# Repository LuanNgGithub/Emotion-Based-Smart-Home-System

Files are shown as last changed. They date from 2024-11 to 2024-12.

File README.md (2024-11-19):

# Emotion-Adaptive Smart Home
Repository for Emotion-Adaptive Smart Home

[Project management (Team 06)](https://pushgd10re5p.larksuite.com/base/LZFZbZlYla9m4zsmLQGupiIKs9e?table=tbl0MZkUSxeu3IoC&view=vewp7nmiS4)

Check out our Wiki for our latest update!
[Wiki](https://github.com/LuanNgGithub/Emotion-Based-Smart-Home-System/wiki)

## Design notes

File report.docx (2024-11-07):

Project Name: Emotion-Based Smart Home System

Current Progress: Today, we successfully set up the environment on the Jetson Orin Nano and configured the GPIO ports. For an initial test, we used a breadboard with an LED (since we haven't purchased a light strip yet) to demonstrate that the light turns on when a "neutral" expression is detected.

Technical Breakthroughs:

1. Successfully accessed the camera for real-time video streaming.
2. Implemented YOLO-based emotion detection in real-time to analyze facial expressions in the video feed.
3. Enabled LED control based on detected emotional states, achieving a basic emotional feedback mechanism.

Code Implementation: Our code employs a voting mechanism to aggregate emotions over a defined window. When "Happy" exceeds a set threshold, the GPIO interface controls the LED to turn on. Key modules include:

1.Real-time video processing and emotion detection.

2.Emotion voting mechanism based on a sliding window to ensure accurate feedback.

3.GPIO control for LED response, triggering based on the detection of specific emotions (e.g., " neutral ").

Next Steps: We plan to purchase a light strip to extend the system, enabling it to display different colors as feedback for various emotions, enhancing both interactivity and expressiveness.

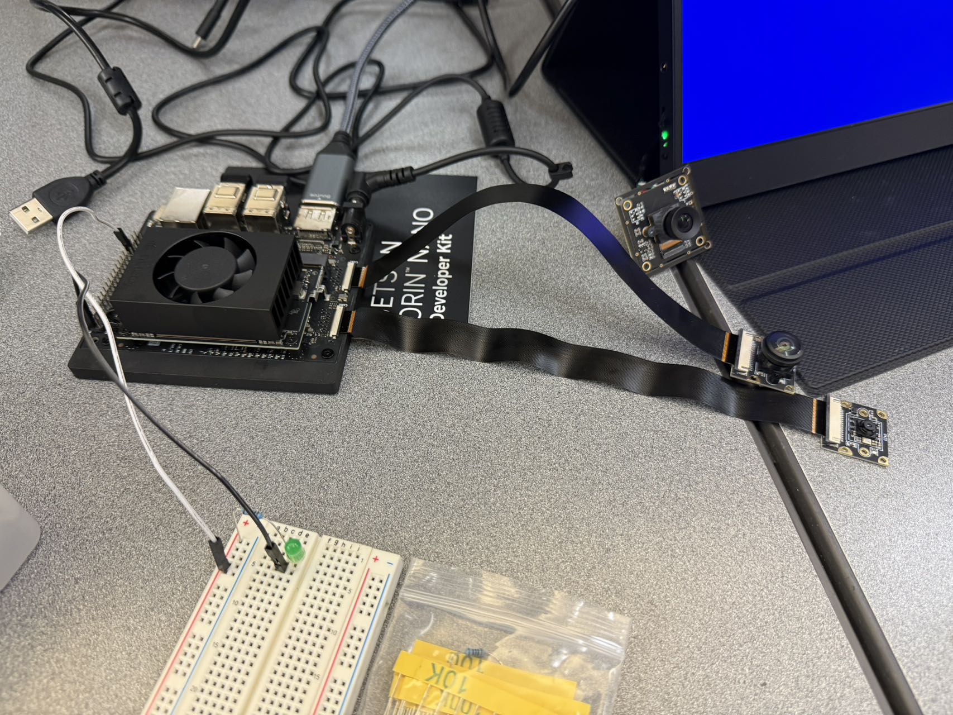
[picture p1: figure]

The image shows our Jetson Orin Nano board, LED, and the camera setup demonstrating real-time emotion feedback

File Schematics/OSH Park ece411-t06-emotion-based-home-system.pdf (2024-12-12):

## OSH Park ~ ece411-t06-emotion-based-home-system

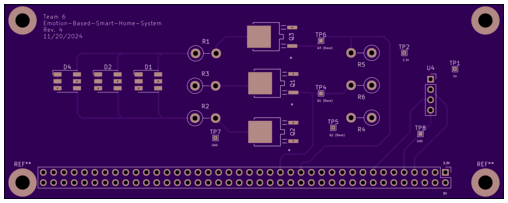
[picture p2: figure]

### Board Top

This shows the final manufactured board as if you held it in your hand.

Your design should show gold copper, purple mask, white silk, black drills, and the board outline.

Internal cutouts are indicated by a black outline but are not filled in.

If the image here is entirely white, you'll want to find and fix any gaps in the board outline.

There should be no dimension or measurement ruler

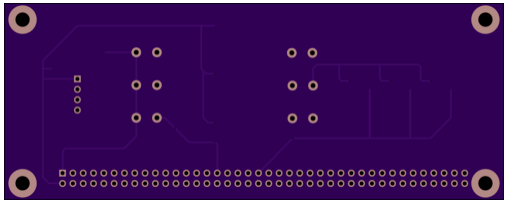
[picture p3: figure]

### Board Bottom

This shows the final manufactured board as if you held it in your hand.

Your design should show gold copper, purple mask, white silk, black drills, and the board outline.

Internal cutouts are indicated by a black outline but are not filled in.

If the image here is entirely white, you'll want to find and fix any gaps in the board outline.

There should be no dimension or measurement ruler

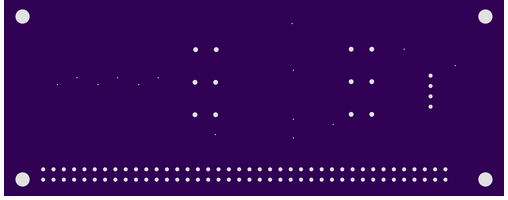
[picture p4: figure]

Rendered from "411 Schematic-PTH.drl"

### Drills

Drills should show up as white circles or dots on a purple background.

Drill files should be NC Drill or Excellon format files. Multiple files will be accepted, and merged into one for fabrication.

Drill hits that pass through copper will be plated. All other drill hits will be non-plated.

Most drill formats are detected and displayed as you'd see on the board. If your drills look incorrect, try exporting with INCH units and either No Zero Suppression or Leading Zero Suppression.

Drill slots and "oval" drills included as part of the drill file are supported. Most design tools do this when using the tool's native slot commands. Supported slots will appear on this preview.
Note, it's possible to use this supported callout in an unsupported way. See our Cutouts and Slots (https://docs.oshpark.com/submitting-orders/cutouts-and-slots/) page for details regarding unsupported applications of slot drill commands.

Drills sizes below our minimums will be increased to the minimum size. See the design rules (https://docs.oshpark.com/services/) or our drills help page. (https://docs.oshpark.com/submitting-orders/drill-specs/) for additional details on drill specs.
Additionally, the following are not supported.
- Overlapping drill hits
- Blind or buried vias

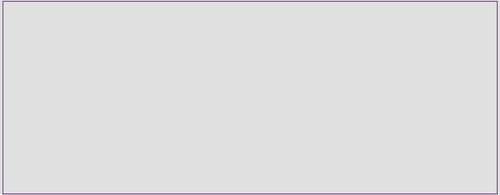
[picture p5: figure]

Rendered from "build3/411 Schematic-Edge_Cuts.gbr"

### Board Outline

The board outline should be a watertight purple outline showing at least the edge of the board with no gaps.

We will cut non-rectangular board shapes, but you will be billed for the smallest rectangle that will encompass the design.
As an example, a 2in diameter circle is billed the same as a 2in by 2in square.

Non-plated Board Cutouts (https://docs.oshpark.com/submitting-orders/board-outline/) can be represented on the board outline layer, with some limitations.
Slots are unsupported when indicated on the board outline layer, but usually work. To make slots with full support, use Drill Slots (https://docs.oshpark.com/submitting-orders/slots/) on the drill layer.

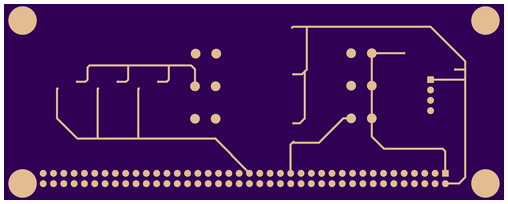
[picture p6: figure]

Rendered from "build3/411 Schematic-B_Cu.gbr"

### Bottom Layer

This layer should appear 'mirrored' as if you were looking down on it through the board from the top.

We will place copper everywhere we see gold color on this layer.

If you are using Altium Designer or Altium CircuitMaker, carefully examine the board to make sure there are no shorts from the mechanical layers being included on this layer. See here (https://docs.oshpark.com/design-tools/altium-designer/) for more.

If you are using Eagle, be aware that airwires are not the same as routed traces. If there are no copper links between pads showing on this layer, please review your .brd file for airwires.

See our design tools pages (https://docs.oshpark.com/design-tools/) for more.

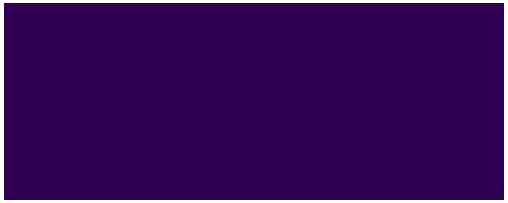
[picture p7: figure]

Rendered from "build3/411 Schematic-B_Silkscreen.gbr"

### Bottom Silk Screen

This layer should appear 'mirrored' as if you were looking down on it through the board from the top.

We will ignore the portion of the silkscreen that extends beyond the board outline.

We will automatically remove any silkscreen that crosses drilled holes or exposed copper.

If a logo isn't showing up on this layer, try changing your design tool import settings to create that silk image with 400 DPI or less, or check out our Eagle-specific import-bmp script (https://docs.oshpark.com/submitting-orders/import-bmp/) instructions.

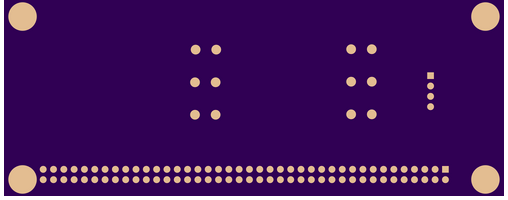
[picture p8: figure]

Rendered from "build3/411 Schematic-B_Mask.gbr"

### Bottom Solder Mask

This layer should appear 'mirrored' as if you were looking down on it through the board from the top.

Soldermask layers show us where to remove the purple solder resist. The gold-colored areas will be exposed on the final board, and purple areas will be covered.

If you submitted an empty file, we won't remove any mask so this entire side of the board will be covered in purple soldermask

To expose the entire board, submit this file with a single polygon that covers the entire board. We will remove all mask everywhere and expose all the copper and board substrate.

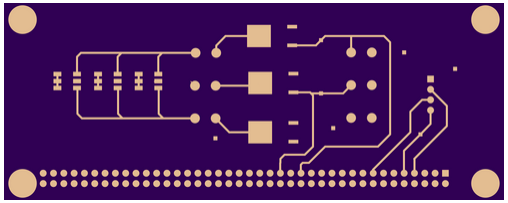
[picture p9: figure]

Rendered from "build3/411 Schematic-F_Cu.gbr"

### Top Layer

We will place copper everywhere we see gold color on this layer.

If you are using Altium Designer or Altium CircuitMaker, carefully examine the board to make sure there are no shorts from the mechanical layers being included on this layer. See here (https://docs.oshpark.com/design-tools/altium-designer/) for more.

If you are using Eagle, be aware that airwires are not the same as routed traces. If there are no copper links between pads showing on this layer, please review your .brd file for airwires.

See our design tools pages (https://docs.oshpark.com/design-tools/) for more.

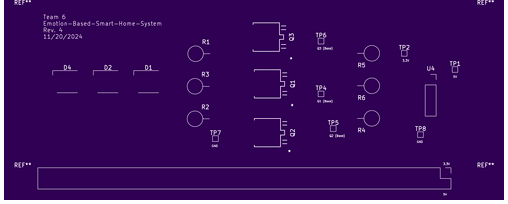
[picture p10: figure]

Rendered from "build3/411 Schematic-F_Silkscreen.gbr"

### Top Silk Screen

We will ignore the portion of the silkscreen that extends beyond the board outline.

We will automatically remove any silkscreen that crosses drilled holes or exposed copper.

If a logo isn't showing up on this layer, try changing your design tool import settings to create that silk image with 400 DPI or less, or check out our Eagle-specific import-bmp script (https://docs.oshpark.com/submitting-orders/import-bmp/) instructions.

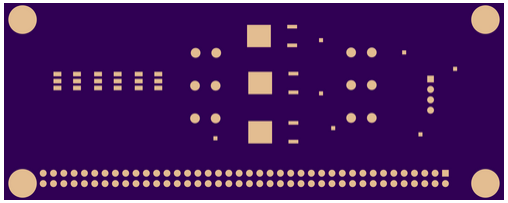
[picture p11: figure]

Rendered from "build3/411 Schematic-F_Mask.gbr"

### Top Solder Mask

Soldermask layers show us where to remove the purple solder resist. The gold-colored areas will be exposed on the final board, and purple areas will be covered.

If you submitted an empty file, we won't remove any mask so this entire side of the board will be covered in purple soldermask

To expose the entire board, submit this file with a single polygon that covers the entire board. We will remove all mask everywhere and expose all the copper and board substrate.

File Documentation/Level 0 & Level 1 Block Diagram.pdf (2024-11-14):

Level 0 Block Diagram

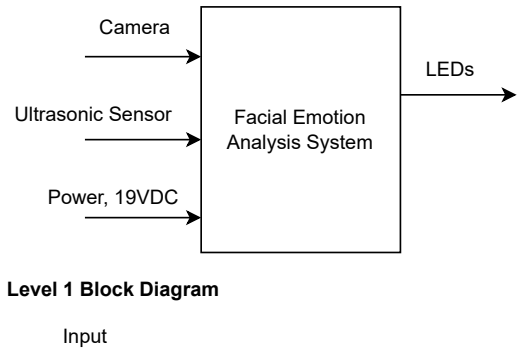
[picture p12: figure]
LEDs; Facial Emotion Analysis System; Camera; Ultrasonic Sensor; Input; Power, 19VDC; Level 1 Block Diagram
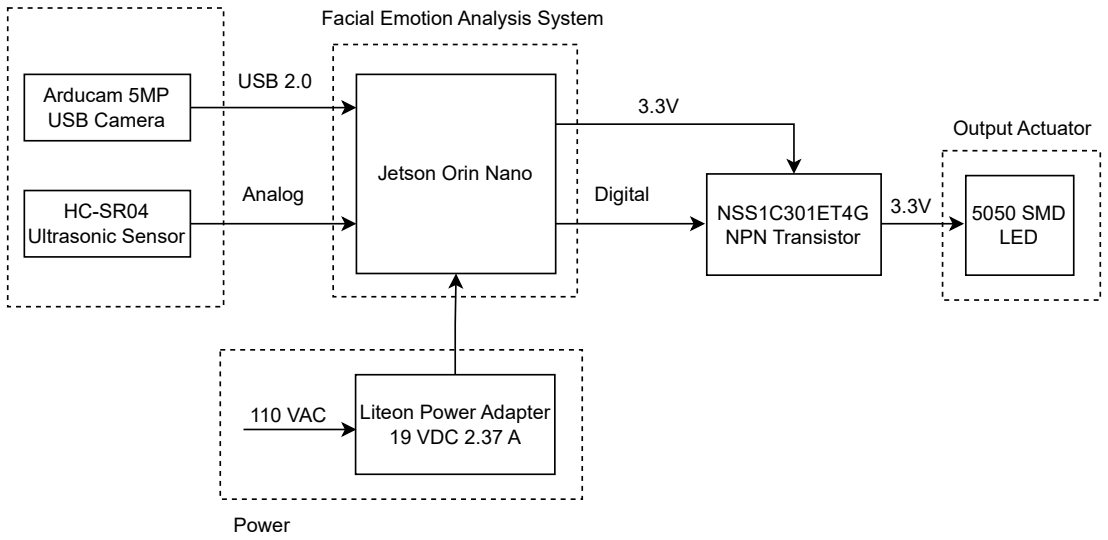
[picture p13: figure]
Jetson Orin Nano; HC-SR04 Ultrasonic Sensor; Arducam 5MP USB Camera; USB 2.0; Analog; Digital; Facial Emotion Analysis System; Liteon Power Adapter 19 VDC 2.37 A; 110 VAC; NSS1C301ET4G NPN Transistor; 5050 SMD LED; Output Actuator; Power

Team 6 - Emotion-Based-Smart-Home-System Kamal, Kilo, Samuel, Luan

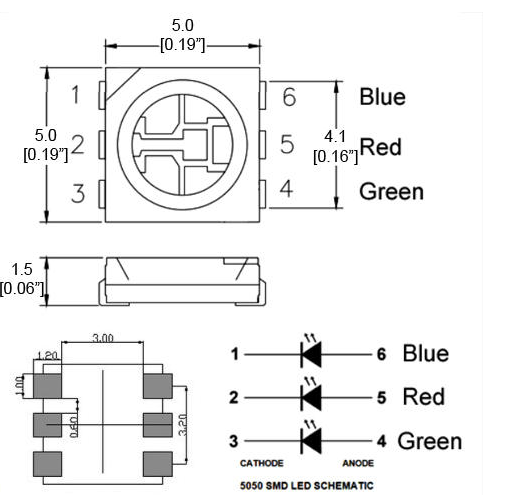
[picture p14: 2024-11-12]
Documentation/5050 SMD LED Pinout.png

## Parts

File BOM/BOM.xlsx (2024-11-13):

Bill Of Materials for: 06 Emotion-Based-Smart-Home-System
Last modified: 11/12/2024
PCB verison: #1
BOM revision: #1
Cnt | Name | P/NP | Mfg | Mfg PN | Description | Dist | Dist Part Number | Cost Ea. | Cost Total
1 | NVIDIA® Jetson Orin™ Nano Developer Kit | P | NVIDIA | J3010 | a compact edge AI board | Seeed Studio | 102110839 | $499 | $499
1 | NVMe M.2 2280 SSD 1TB | P | Kioxia | M.2280 1TB | 1TB PCIe NVMe Gen 3x4 SSD, includes a heatsink suitable for 2280 SSDs | Seeed Studio | 112990267 | $74.99 | $74.99
1 | Arducam 5MP Autofocus USB Camera Module | P | Arducam | B0441 | 2592(H)×1944(V)@30fps, mini camera for Linux | Amazon | B08ZR8KNXT | $34.99 | $34.99
1 | Chanzon 100 pcs 5050 WS2812B SMD RGB Tricolor LED Diode Lights | P | Chanzon | WS2812B | RGB multicolor LED, 6-pin, 16mA, DC 3.7V-5.3V, wide viewing angle of 120 degrees | Amazon | B09J4KDYY3 | $9.99 | $9.99
10 | NSS1C301ET4G | P | Onsemi | NSS1C301ET4G | NPN Transistor, 100V, 3A, DPAK, 2.1W Surface Mount | Digi-Key | NSS1C301ET4GOSCT-ND | $0.81 | $8.10
1 | Ultrasonic Sensor Module HCSR-04 | NP | Gearbox Labs | PART HCSR-04 | Ultrasonic Sensor, 40kHz, Generic Distance Sensor | Digi-Key | 4166-PARTHCSR-04-ND | $5.00 | $5.00
1 | IRLB8721PbF | P | Infineon Technologies | IRLB8721PbF | N-Channel MOSFET, 30V, 62A, TO-220AB, 65W, Through Hole | Digi-Key | IRLB8721PBF-ND | $1.57 | $1.57

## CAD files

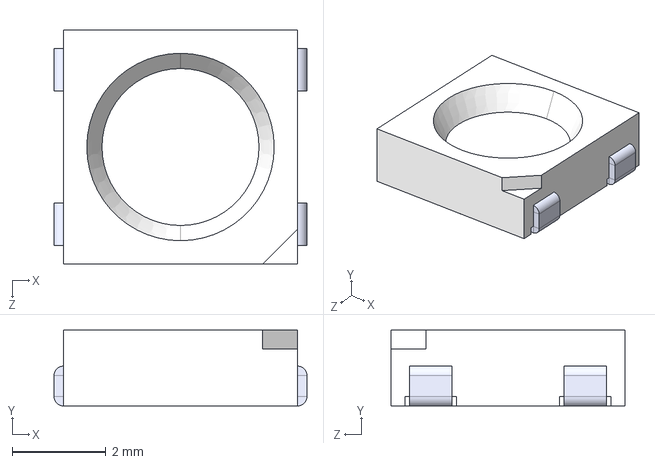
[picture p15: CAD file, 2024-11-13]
Footprints/SMD-RGB-HI-LIGHT_6P-L5.0_W5.0_H1.5MM_/SMD-RGB-HI-LIGHT_6P-L5.0_W5.0_H1.5MM_.step
5.40 x 1.62 x 5.00 mm

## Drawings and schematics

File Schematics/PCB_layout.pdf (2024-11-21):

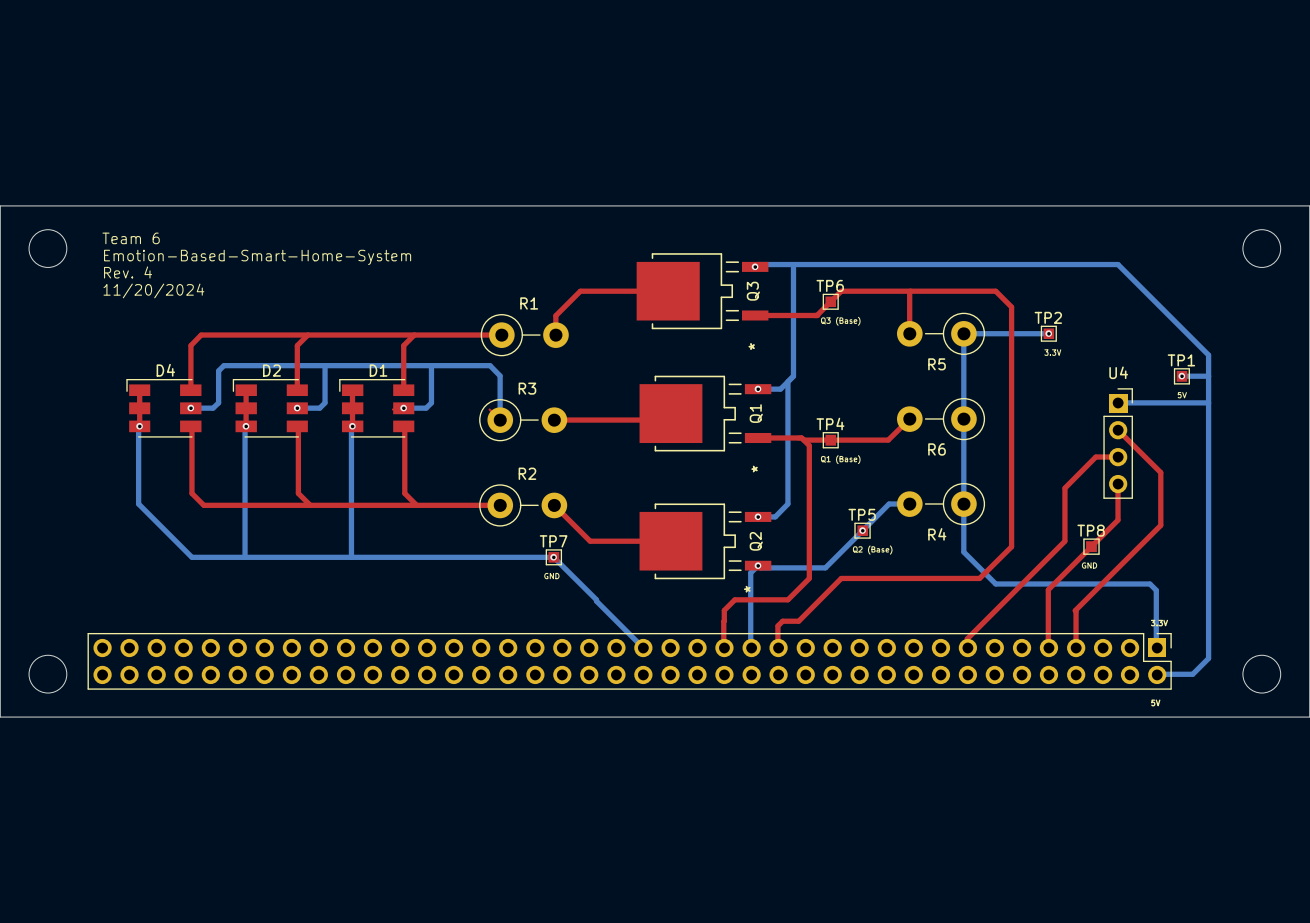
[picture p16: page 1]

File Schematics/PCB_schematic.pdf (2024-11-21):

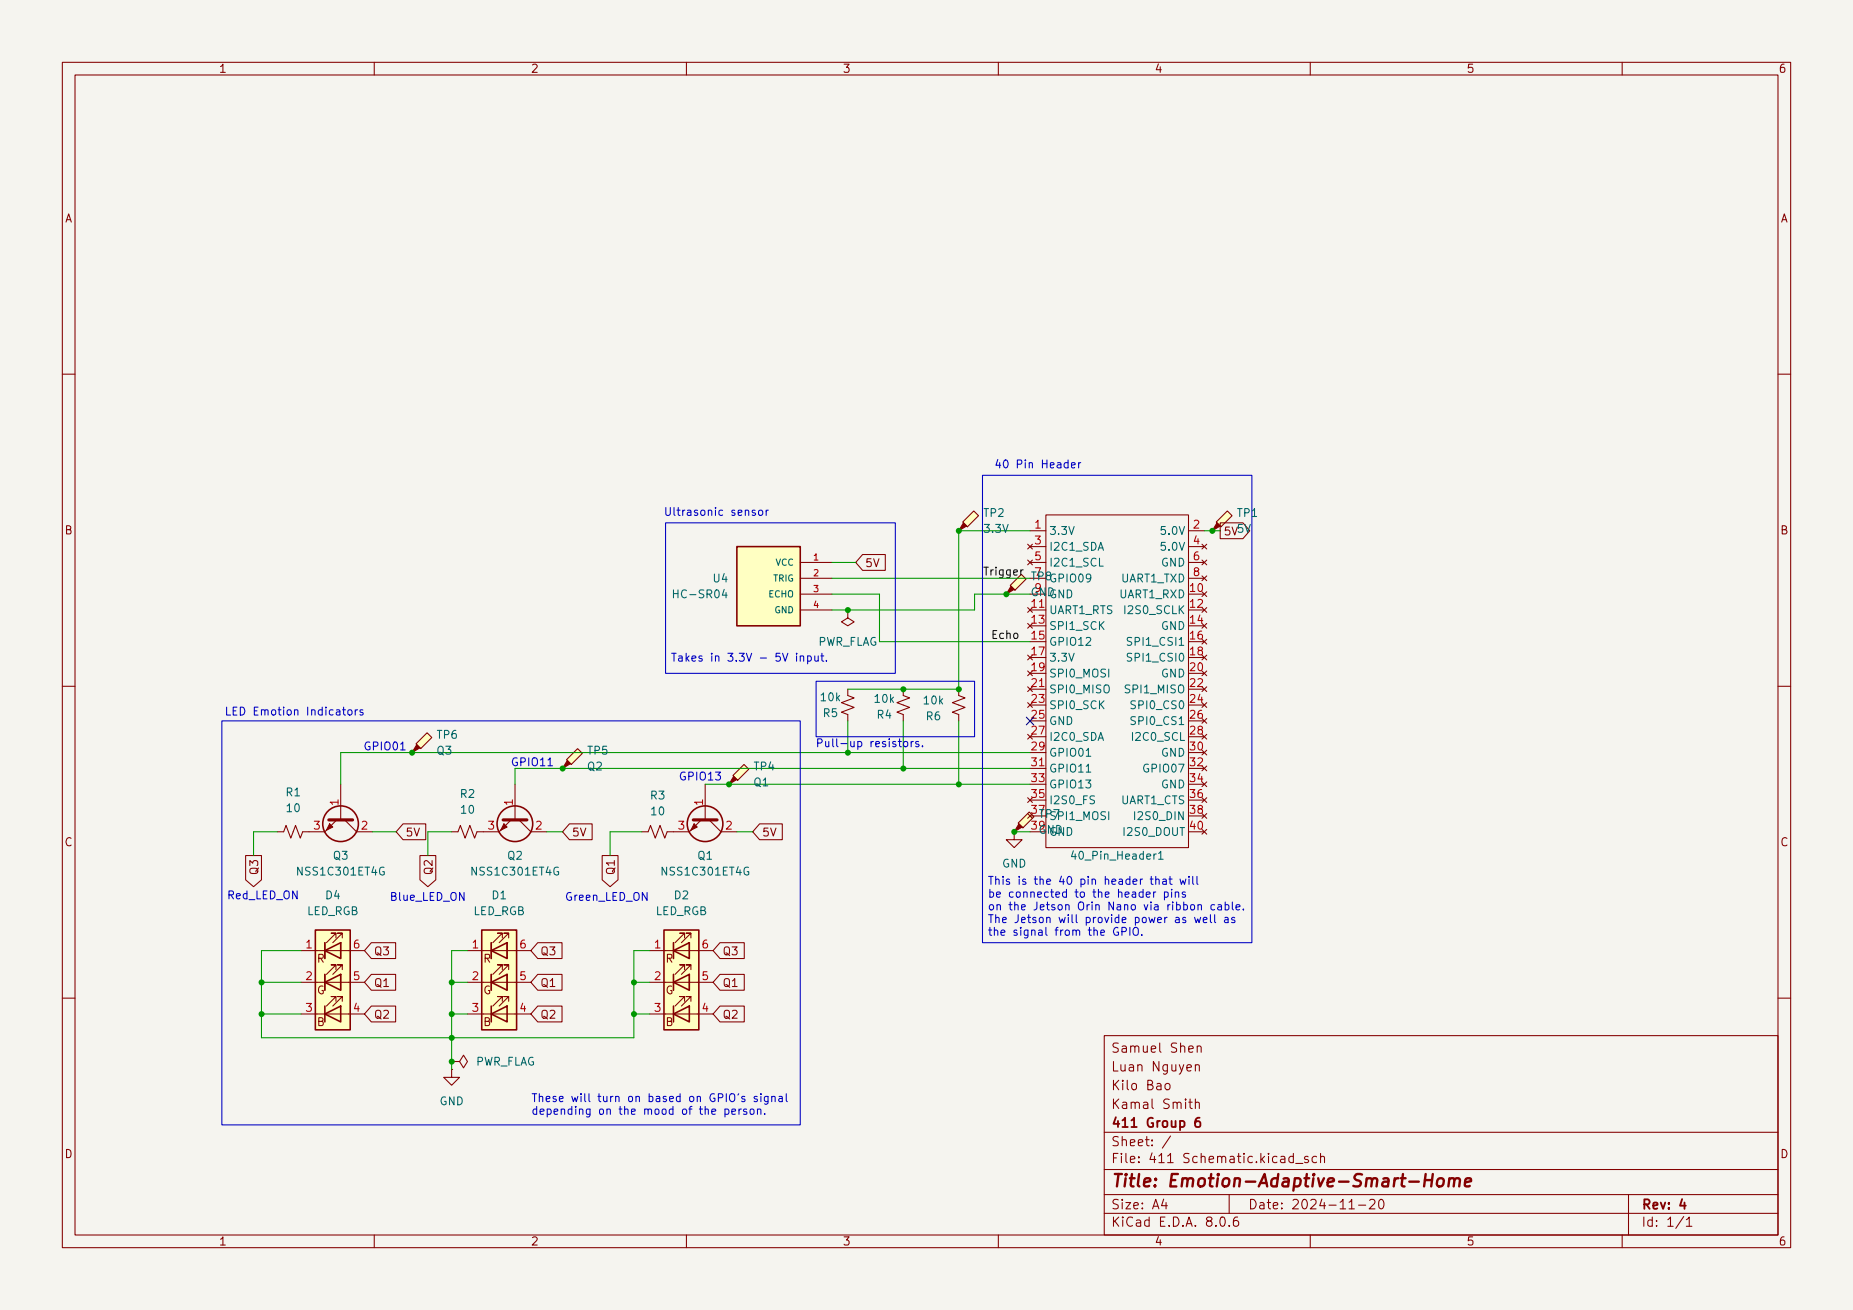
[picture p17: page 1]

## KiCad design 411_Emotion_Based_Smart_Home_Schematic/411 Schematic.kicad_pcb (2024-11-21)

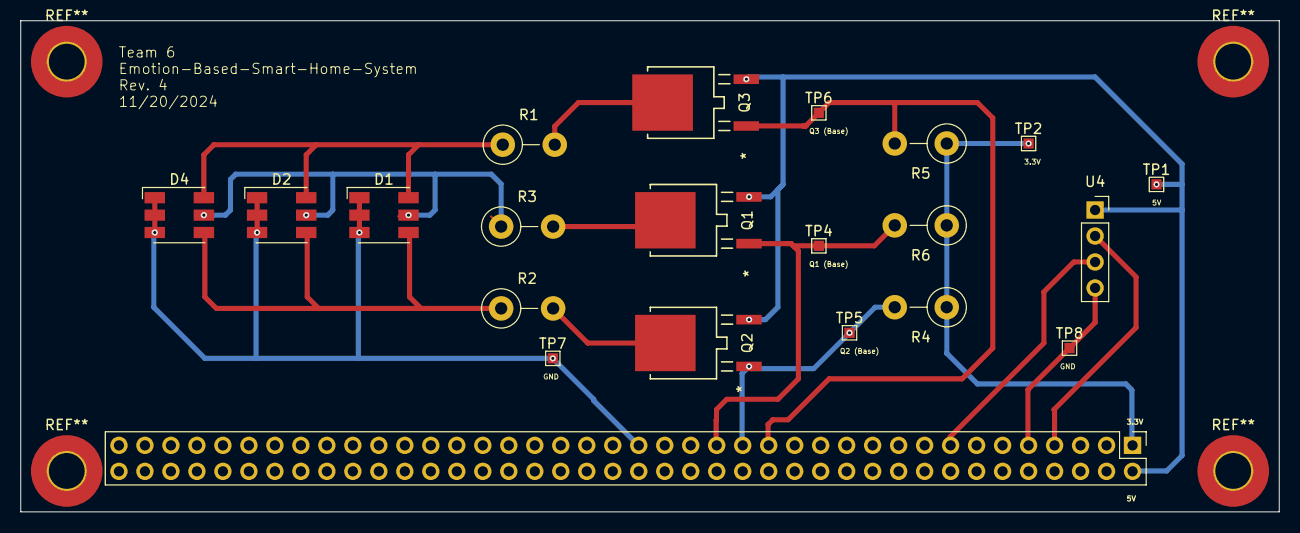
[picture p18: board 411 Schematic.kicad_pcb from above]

Board: 2 copper layers, 123.0 x 48.0 mm, 21 parts (0 on the bottom side), 15 nets.

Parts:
40_Pin_Header1: PinHeader_2x40_P2.54mm_Vertical
D1, D2, D4: LED_RGB; LED_RGB_5050-6
Q1, Q2, Q3: NSS1C301ET4G; DPAK-4_6P22X6P73_ONS
R1, R2, R3: 10; R_Axial_DIN0411_L9.9mm_D3.6mm_P5.08mm_Vertical
R4, R5, R6: 10k; R_Axial_DIN0411_L9.9mm_D3.6mm_P5.08mm_Vertical
TP1: 5V; TestPoint_Pad_1.0x1.0mm
TP2: 3.3V; TestPoint_Pad_1.0x1.0mm
TP4: Q1; TestPoint_Pad_1.0x1.0mm
TP5: Q2; TestPoint_Pad_1.0x1.0mm
TP6: Q3; TestPoint_Pad_1.0x1.0mm
TP7, TP8: GND; TestPoint_Pad_1.0x1.0mm
U4: HC-SR04; PinSocket_1x04_P2.54mm_Vertical

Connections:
5V: 40_Pin_Header1.2 (5.0V), Q1.2 (C), Q2.2 (C), Q3.2 (C), TP1.1, U4.1 (VCC)
/Echo: 40_Pin_Header1.15 (GPIO12), U4.3 (ECHO)
/Trigger: 40_Pin_Header1.7 (GPIO09), U4.2 (TRIG)
GND: 40_Pin_Header1.39 (GND), D1.1 (RK), D1.2 (GK), D1.3 (BK), D2.1 (RK), D2.2 (GK), D2.3 (BK), D4.1 (RK), D4.2 (GK), D4.3 (BK), TP7.1
unnamed: 40_Pin_Header1.1 (3.3V), R4.1, R5.1, R6.1, TP2.1
unnamed: 40_Pin_Header1.29 (GPIO01), Q3.1 (B), R5.2, TP6.1
unnamed: 40_Pin_Header1.31 (GPIO11), Q2.1 (B), R4.2, TP5.1
unnamed: 40_Pin_Header1.33 (GPIO13), Q1.1 (B), R6.2, TP4.1
unnamed: Q1.3 (E), R3.2
unnamed: Q2.3 (E), R2.2
unnamed: Q3.3 (E), R1.2
unnamed: 40_Pin_Header1.9 (GND), TP8.1, U4.4 (GND)
Q1: D1.5 (GA), D2.5 (GA), D4.5 (GA), R3.1
Q2: D1.4 (BA), D2.4 (BA), D4.4 (BA), R2.1
Q3: D1.6 (RA), D2.6 (RA), D4.6 (RA), R1.1

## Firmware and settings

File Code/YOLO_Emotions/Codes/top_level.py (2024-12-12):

import os
import time
import subprocess
import logging
import Jetson.GPIO as GPIO

#sudo systemctl enable top_level.service
#sudo systemctl stop top_level.service



# 配置日志
logging.basicConfig(filename="/home/jetson/Desktop/recording.log",
                    level=logging.INFO,
                    format="%(asctime)s - %(levelname)s - %(message)s")

# 初始化 GPIO, 用于状态显示和超声波传感器
LED_STATUS_PIN = 15  # 显示进程状态的 LED 引脚
GPIO_TRIGGER = 7  # 超声波传感器 Trig 引脚###################Test the trigger first
GPIO_ECHO = 32  # 超声波传感器 Echo 引脚


GPIO.cleanup()
GPIO.setmode(GPIO.BOARD)
GPIO.setup(LED_STATUS_PIN, GPIO.OUT, initial=GPIO.LOW)
GPIO.setup(GPIO_TRIGGER, GPIO.OUT, initial=GPIO.LOW)
GPIO.setup(GPIO_ECHO, GPIO.IN)

# 超声波测距函数
def measure_distance():
    # 发送高电平信号到 Trig 引脚
    GPIO.output(GPIO_TRIGGER, GPIO.HIGH)
    time.sleep(0.00001)
    GPIO.output(GPIO_TRIGGER, GPIO.LOW)

    # 记录发送超声波的时刻
    start_time = time.time()
    while GPIO.input(GPIO_ECHO) == 0:
        start_time = time.time()

    # 记录接收到返回超声波的时刻
    stop_time = time.time()
    while GPIO.input(GPIO_ECHO) == 1:
        stop_time = time.time()

    # 计算往返时间并转换为距离 (cm)
    time_elapsed = stop_time - start_time
    distance = (time_elapsed * 34300) / 2
    return distance





# 控制 LED 状态
#def set_led_status(is_running):
 #   GPIO.output(LED_STATUS_PIN, GPIO.HIGH if is_running else GPIO.LOW)
  #  GPIO.output(LED_PIN, GPIO.HIGH)  # 设置 LED 引脚为高电平，保持亮




# 主进程循环
def main_loop():
    yolo_process = None
    GPIO.output(LED_STATUS_PIN, GPIO.HIGH)  # 设置 LED 引脚为高电平，保持亮
    try:
        while True:
            # 检查 YOLO 子进程是否已退出
            if yolo_process is not None and yolo_process.poll() is None:
                logging.info("YOLO process is still running.")
                time.sleep(1)  # 延迟检查
                continue

            # 测量距离
            dist = measure_distance()
            logging.info(f"Measured distance: {dist:.2f} cm")

            # 检查距离触发条件80cm
            if dist < 80:
                logging.info("Trigger condition met (distance < 80cm). Starting YOLO process...")
                yolo_process = subprocess.Popen(["python3", "/home/jetson/Documents/test/programm.py"])
          
            else:

                logging.info("No trigger condition met. Waiting...")

            time.sleep(1)  # 主循环间隔

    except KeyboardInterrupt:
        logging.info("Process manager stopped by user.")
    except Exception as e:
        logging.error(f"Unexpected error: {e}")
    finally:
        if yolo_process is not None:
            yolo_process.terminate()
        GPIO.cleanup()


if __name__ == "__main__":
    main_loop()

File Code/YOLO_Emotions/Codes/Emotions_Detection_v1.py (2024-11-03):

import cv2
from ultralytics import YOLO  # 确保这个import语句与您的实际环境相匹配

# 加载YOLOv8模型：人脸检测模型和表情识别模型
face_model = YOLO('/Users/muse/Documents/YOLO_Emotions/Test/weights/yolo_face.pt')  # 人脸检测模型
emotion_model = YOLO('/Users/muse/Documents/YOLO_Emotions/Test/weights/yolo11s/best.pt')  # 表情识别模型

# 打开摄像头
cap = cv2.VideoCapture(0)

# 设置视频流的分辨率为1080p (1920x1080)
cap.set(cv2.CAP_PROP_FRAME_WIDTH, 1920)
cap.set(cv2.CAP_PROP_FRAME_HEIGHT, 1080)

# 循环遍历视频帧
while cap.isOpened():
    # 从视频读取一帧
    success, frame = cap.read()

    if success:
        # 在帧上运行人脸检测，并设置置信度阈值和NMS IOU阈值
        face_results = face_model(frame, conf=0.7, iou=0.5)

        # 迭代每个检测到的人脸框
        for face in face_results:
            # 获取人脸的坐标框信息
            for box in face.boxes:
                # 提取人脸区域
                x1, y1, x2, y2 = map(int, box.xyxy[0])
                face_region = frame[y1:y2, x1:x2]

                # 在人脸区域内运行表情检测，并设置置信度阈值和NMS IOU阈值
                emotion_results = emotion_model(face_region, conf=0.7, iou=0.5)

                # 在人脸区域上展示表情检测的结果
                if len(emotion_results) > 0:
                    annotated_face = emotion_results[0].plot()

                    # 将注释后的脸部区域重新放回到原图上
                    frame[y1:y2, x1:x2] = annotated_face

        # 展示带注释的帧（包含人脸和表情）
        cv2.imshow("Emotions Detection", frame)

        # 如果按下'q'则退出循环
        if cv2.waitKey(1) & 0xFF in [27, ord('q')]:
            break
    else:
        # 如果视频结束则退出循环
        break

# 释放视频捕获对象并关闭显示窗口
cap.release()
cv2.destroyAllWindows()

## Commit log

2024-10-31 Create Ultrasonic Sensor
2024-11-07 Current updated schematic
    [Emotion-Based-Smart-Home-System.kicad_sch]
2024-11-07 Current Schematic
    This is the schematic that Luan and Kamal are actively working on
    [Emotion-Based-Smart-Home-System.kicad_sch]
2024-11-07 Updated Kicad design
    This is our updated kicad, we still need to add the speaker and finish the camera
    [Emotion-Based-Smart-Home-System.kicad_sch]
2024-11-07 Updated again
    Fixed an error and made the GND on the USB camera passive
    [Emotion-Based-Smart-Home-System.kicad_sch]
2024-11-07 Entire design folder
    We had to move this into it's own seperate file to get the PCB design to work. Will fix names later
    [411 Schematic.kicad_pcb, 411 Schematic.kicad_sch, Emotion-Based-Smart-Home-System.kicad_sch]
2024-11-07 Updating our Schematic and Layout
    Altering things in the schematic and layout before we turn this in
    [411 Schematic.kicad_pcb]
2024-11-07 Delete 411_Emotion_Based_Smart_Home_Schematic/~411 Schematic.kicad_sch.lck
    Removing the Lock file
2024-11-07 Delete 411_Emotion_Based_Smart_Home_Schematic/~411 Schematic.kicad_pcb.lck
    Removing this lock file
2024-11-09 Added folder for ultrasonic sensor.
2024-11-09 Organized folders.
    [411 Schematic.kicad_pcb, 411 Schematic.kicad_sch, Emotion-Based-Smart-Home-System.kicad_sch]
2024-11-12 Added spec sheet for LED and BJT.
2024-11-13 Added folder for BOM and Footprint.
2024-11-13 Updating schematic
    Testing if this works
2024-11-13 Added LED RGB footprint
    [SMD-RGB-HI-LIGHT_6P-L5.0_W5.0_H1.5MM_.step]
2024-11-14 5050 LED Schematic.drawio
2024-11-14 5050 LED and Transistor Schematic.drawio
2024-11-14 Updating what I have of schematic
    [411 Schematic.kicad_sch]
2024-11-14 Updated the schematic.
    [411 Schematic.kicad_pcb, 411 Schematic.kicad_sch, Emotion-Based-Smart-Home-System.kicad_sch]
2024-11-14 Fixing Errors
    [411 Schematic.kicad_sch]
2024-11-14 No Errors!
    This PCB currently has no error in ERC
    [411 Schematic.kicad_sch]
2024-11-14 PCB Rough route and schematic almost finished
    [411 Schematic.kicad_pcb, 411 Schematic.kicad_sch]
2024-11-14 Modified size of PCB frame
    [411 Schematic.kicad_pcb]
2024-11-14 Removing .lck files agian
    [411 Schematic.kicad_pcb]
2024-11-17 Updated schematic.
    [411 Schematic.kicad_pcb, 411 Schematic.kicad_sch, Emotion-Based-Smart-Home-System.kicad_sch]
2024-11-19 Added TP and cleaned up all the traces.
    [411 Schematic.kicad_pcb, 411 Schematic.kicad_sch]
2024-11-21 Updated schematic and layout.
    [411 Schematic.kicad_pcb, 411 Schematic.kicad_sch]
2024-12-12 Updated schematic.
    Added limiting resistors to each GPIO pins.
    [411 Schematic-B_Cu.gbr, 411 Schematic-B_Mask.gbr, 411 Schematic-B_Paste.gbr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]
2024-12-12 Updated schematic again. Should work now.
    [411 Schematic-B_Cu.gbr, 411 Schematic-B_Mask.gbr, 411 Schematic-B_Paste.gbr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]
2024-12-13 Updated schematic.
    Changed from Pin 15 to Pin 32.
    [411 Schematic.kicad_sch]
